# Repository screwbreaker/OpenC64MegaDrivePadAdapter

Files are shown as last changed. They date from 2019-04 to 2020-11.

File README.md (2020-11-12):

# OpenC64MegaDrivePadAdapter
OpenC64MegaDrivePadAdapter is an Open Hardware adapter that allows the safe connection of a Sega Mega Drive (known as *Genesis* in the US) controller to a Commodore 64 or Amiga computer.

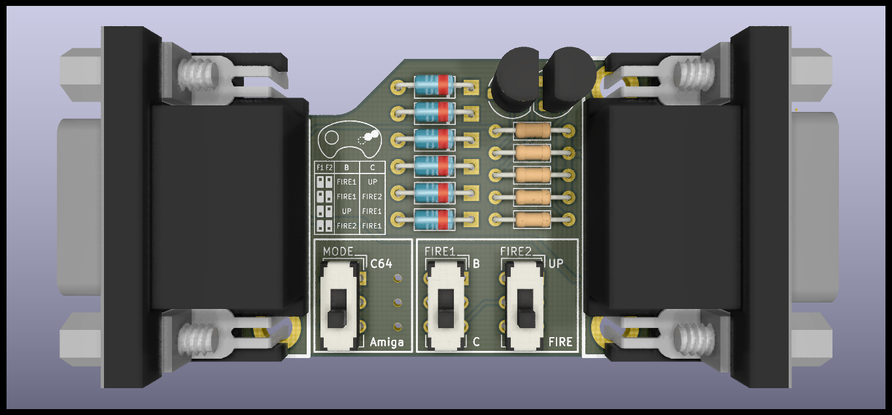
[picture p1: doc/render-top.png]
Board


### Synopsis
This board is a fork of a project of SukkoPera: [github.com/SukkoPera](https://github.com/SukkoPera/), also this document is based on the original version.

The original version of this board can be found here: [github.com/SukkoPera/OpenC64MegaDrivePadAdapter](https://github.com/SukkoPera/OpenC64MegaDrivePadAdapter)

In this version the PCB has a particular shape in order to manage with the Amiga 600 case.
A manual cut of the DB9 connector still required in order to allow this adapter to fit into the A600 port 2. If you are not confident with cut tools, don't do it! A simple extension cable is a perfect and easy solution for this problem. 

This version use switches instead jumpers, this make the configuration much easier, plus now is impossible to set an improper configuration.
Is still recommended to turn off the computer before change the configuration.
The UP direction on the D-PAD is always active, it cannot be disabled. It can be used together with another button configured as UP. An extra diode (D6) is used to separate the two UP lines.

In the older versions of the adapter, sometimes the second button was not recognized by some games, now a transistor is used to fix this issue.
This version is also compatible with the [OpenAmigaJoyMouseSwitcher](https://github.com/SukkoPera/OpenAmigaJoyMouseSwitcher).

Rev 6 also include the mod to allow the amiga to use all the MD pad buttons. Unfortunately at the moment there are no known games or program that can do this. Thanks to SukkoPera for this improvement.

### Summary
Despite being compatible at the physical level (i.e.: they use the same DB-9 connectors), Sega Mega Drive controllers are slightly different from the *Atari-style joysticks* (which the C64 uses) at the electrical level. These differences usually manifest themselves in the fact that certain keyboard keys are not responsive when a Sega Mega Drive pad is connected to a C64 computer, but the CIA chip may also get harmed as a result.

Since I think that the Sega Mega Drive controller is one of the best joypads which ever saw the light, I developed this simple adapter board, which is supposed to sit inbetween the computer and the controller. You should be able to keep it plugged into the computer and then connect the controller to it, but you can also use a joystick extension cord (widely available), if that makes it easier.

Button B will work as the normal fire button, but this adapter also allows using Button C as the second fire button, for those games that support two buttons.

While this all works out of the box on Amiga computers, this adapter also allows to customize the button mapping to a certain degree: for instance, replacing UP with C might make some games more comfortable to play. This might be useful on the Amiga as well, so the adapter also supports an Amiga mode.

In this version the D-PAD UP is always active, it ca be used in games as usual, this is andy for games witch use UP for multiple things: menu, jump, go upstairs, etc.

### Configuration
The board is based on the circuit that was originally published in [issue #5 of Commodore world](https://www.scribd.com/document/8945979/Commodore-World-Issue-05) back in 1994, with a few improvements that will allow an easier gameplay with certain titles.

First of all, be sure to move the C64/Amiga switch to the proper position, before connecting the adapter.

Since most joysticks back in the day only had a single fire button, it was usually used for *firing*, whatever that meant. *Jumping* was usually done with the UP direction of the joystick, which is quite annoying on a joypad.
This is why OpenC64MegaDrivePadAdapter allows you to repurpose the B or C key to jumping, leaving the other button for firing, all at your choice.
It also allows to use C as the second fire button, which is only supported by a few titles. You can even swap B and C, if you prefer.

The switches configurations are showed on a little table printed on the board. F1 and F2 on the table refers to FIRE1 and FIRE2 switches.

The FIRE1 switch select which button to use as FIRE 1, B or C.

The FIRE2 switch select which action the FIRE 2 button must perform, UP (the same of the D-PAD UP) or FIRE.

**ALWAYS TURN YOUR COMPUTER OFF BEFORE MOVING THE CONFIGURATION SWITCHES.**
If you don't follow this rule, **you will probably cause permanent damage to your computer and/or controller**, so **please be careful**, you have been warned.

### Compatibility
This adapter is compatible with every MD gamepad, even the 6 buttons one. And also with the Master System gamepad.

The Mega Drive gamepad is designed to be back compatible with the Master System. B and C on the Mega Drive are BUTTON 1 and BUTTON 2 on the Master System.

To add more buttons on the Mega Drive, SEGA added an extra line (SELECT) wich is toggled HIGH or LOW. The state of this line determinate wich set of buttons the pad must return (B and C or A and START).
Since in this adapter the SELECT line is always HIGH, only the B and C buttons are used.

### License
OpenC64MegaDrivePadAdapter is Open Hardware. If you make any modifications to the board, please contribute them back.

### Support the Project
Since the project is open you are free to get the PCBs made by your preferred manufacturer, however in case you want to support the development, you can order them from PCBWay:

PCB from PCBWay (https://www.pcbway.com/project/shareproject/OpenC64MegaDrivePadAdapter.html)

You get cheap, professionally-made and good quality PCBs, the autor of the board get some credit that will help with this and [other projects](https://www.pcbway.com/project/member/?bmbno=W123483A). You won't even have to worry about the various PCB options, it's all pre-configured for you!

Also, if you still have to register to that site, [you can use this link](https://www.pcbway.com/setinvite.aspx?inviteid=41100) to get some bonus initial credit (and some more to the author).

Again, if you want to use another manufacturer, feel free to, don't feel obligated :).

### Get Support
If you need help or have questions, you can join [the official Telegram group](https://t.me/joinchat/HUHdWBC9J9JnYIrvTYfZmg).

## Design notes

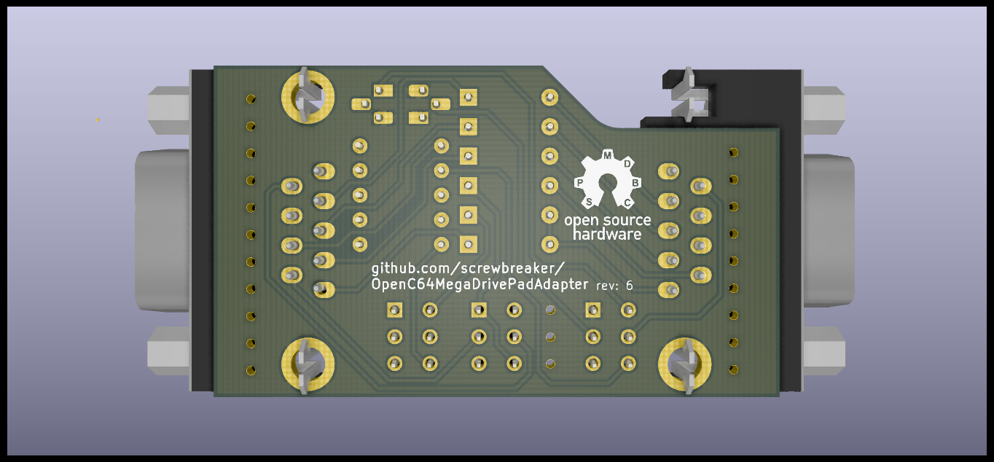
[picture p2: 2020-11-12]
doc/render-bottom.png

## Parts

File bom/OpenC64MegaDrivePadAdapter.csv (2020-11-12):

Id | Designator | Package | Quantity | Designation | Supplier and ref
1 | Q2,Q1 | TO-92_Molded_Narrow | 2 | BC547
2 | D4,D6,D1,D2,D3,D5 | D_DO-35_SOD27_P7.62mm_Horizontal | 6 | 1N4148
3 | R1,R2,R3,R4,R5 | R_Axial_DIN0204_L3.6mm_D1.6mm_P7.62mm_Horizontal | 4 | 10k
4 | S1,S2,S3 | SW_CuK_JS202011CQN_DPDT_Straight | 3 | JS202011CQN
5 | J20 | DB_9M | 1 | DB9_M_TO_PAD
6 | J10 | DB_9F | 1 | DB9_F_TO_C64

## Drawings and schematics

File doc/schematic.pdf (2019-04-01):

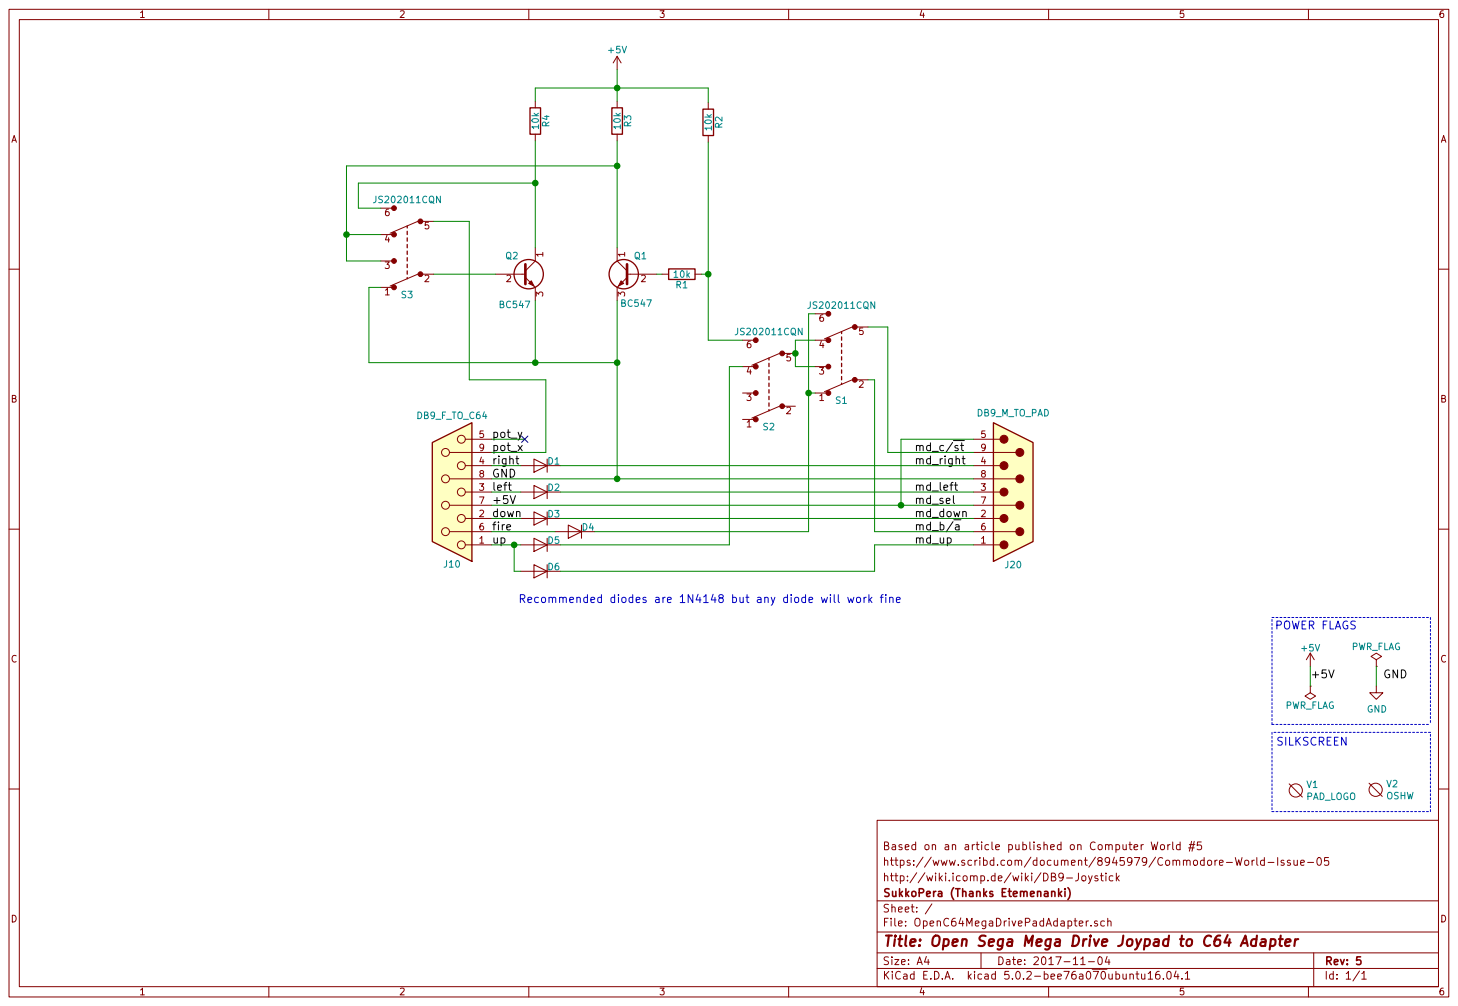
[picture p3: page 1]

J20 DB9_M_TO_PAD Recommended diodes are 1N4148 but any diode will work fine

https://www.scribd.com/document/8945979/Commodore-World-Issue-05
http://wiki.icomp.de/wiki/DB9-Joystick
File: OpenC64MegaDrivePadAdapter.sch Sheet: / SukkoPera (Thanks Etemenanki)

Id: 1/1 Title: Open Sega Mega Drive Joypad to C64 Adapter

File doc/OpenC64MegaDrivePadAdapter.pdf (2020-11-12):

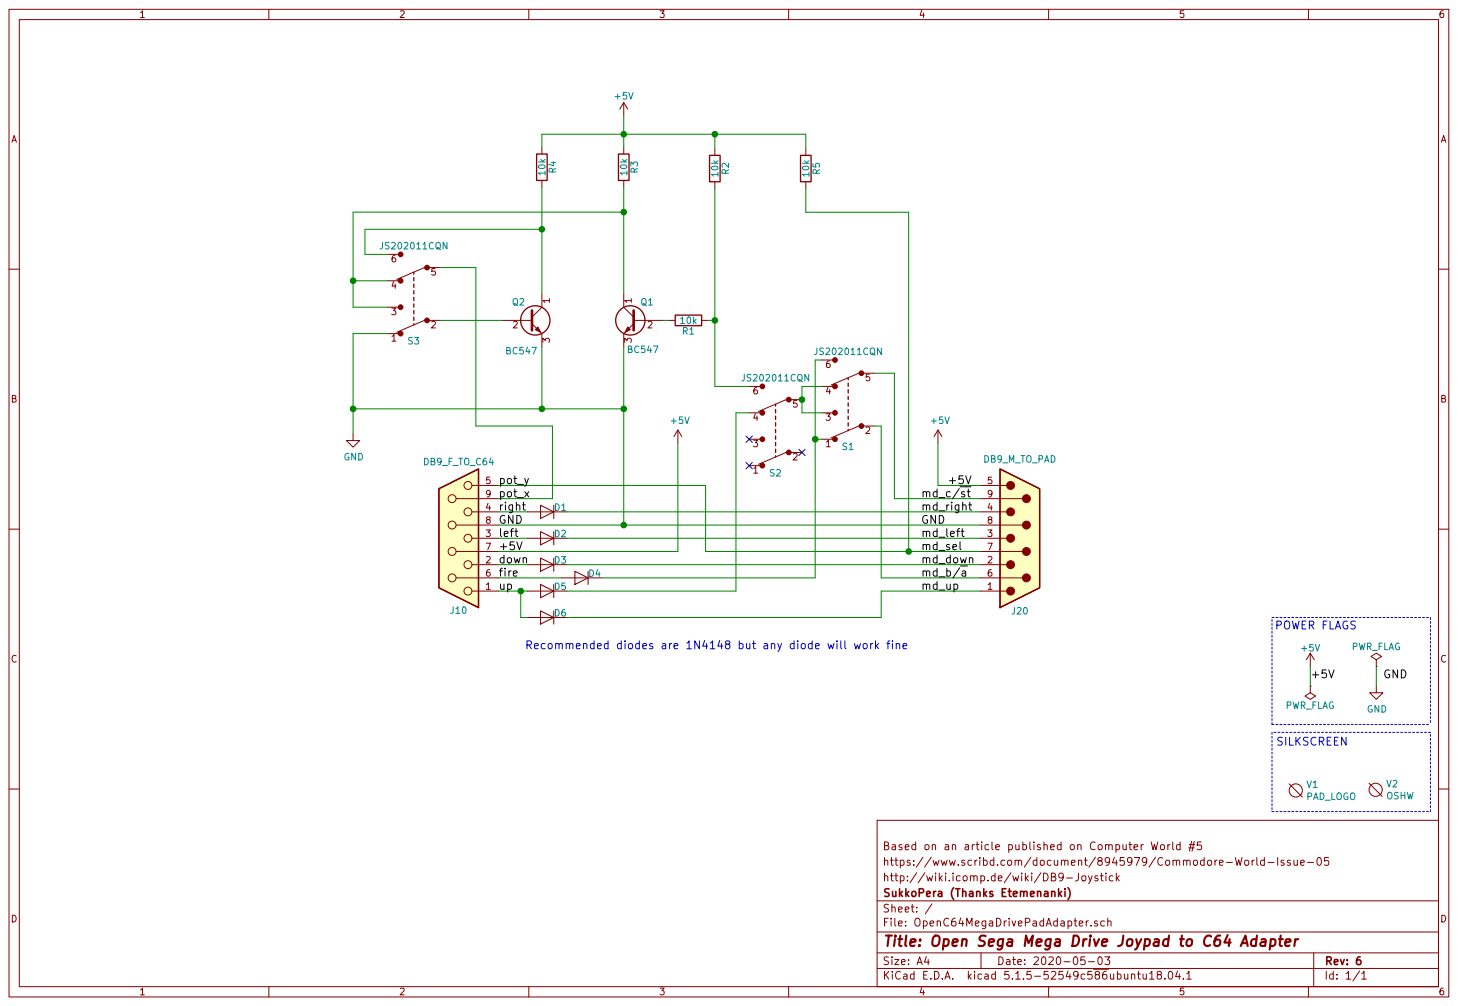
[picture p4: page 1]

Recommended diodes are 1N4148 but any diode will work fine

Based on an article published on Computer World #5
https://www.scribd.com/document/8945979/Commodore-World-Issue-05
http://wiki.icomp.de/wiki/DB9-Joystick
File: OpenC64MegaDrivePadAdapter.sch Sheet: / SukkoPera (Thanks Etemenanki)

Id: 1/1 Title: Open Sega Mega Drive Joypad to C64 Adapter

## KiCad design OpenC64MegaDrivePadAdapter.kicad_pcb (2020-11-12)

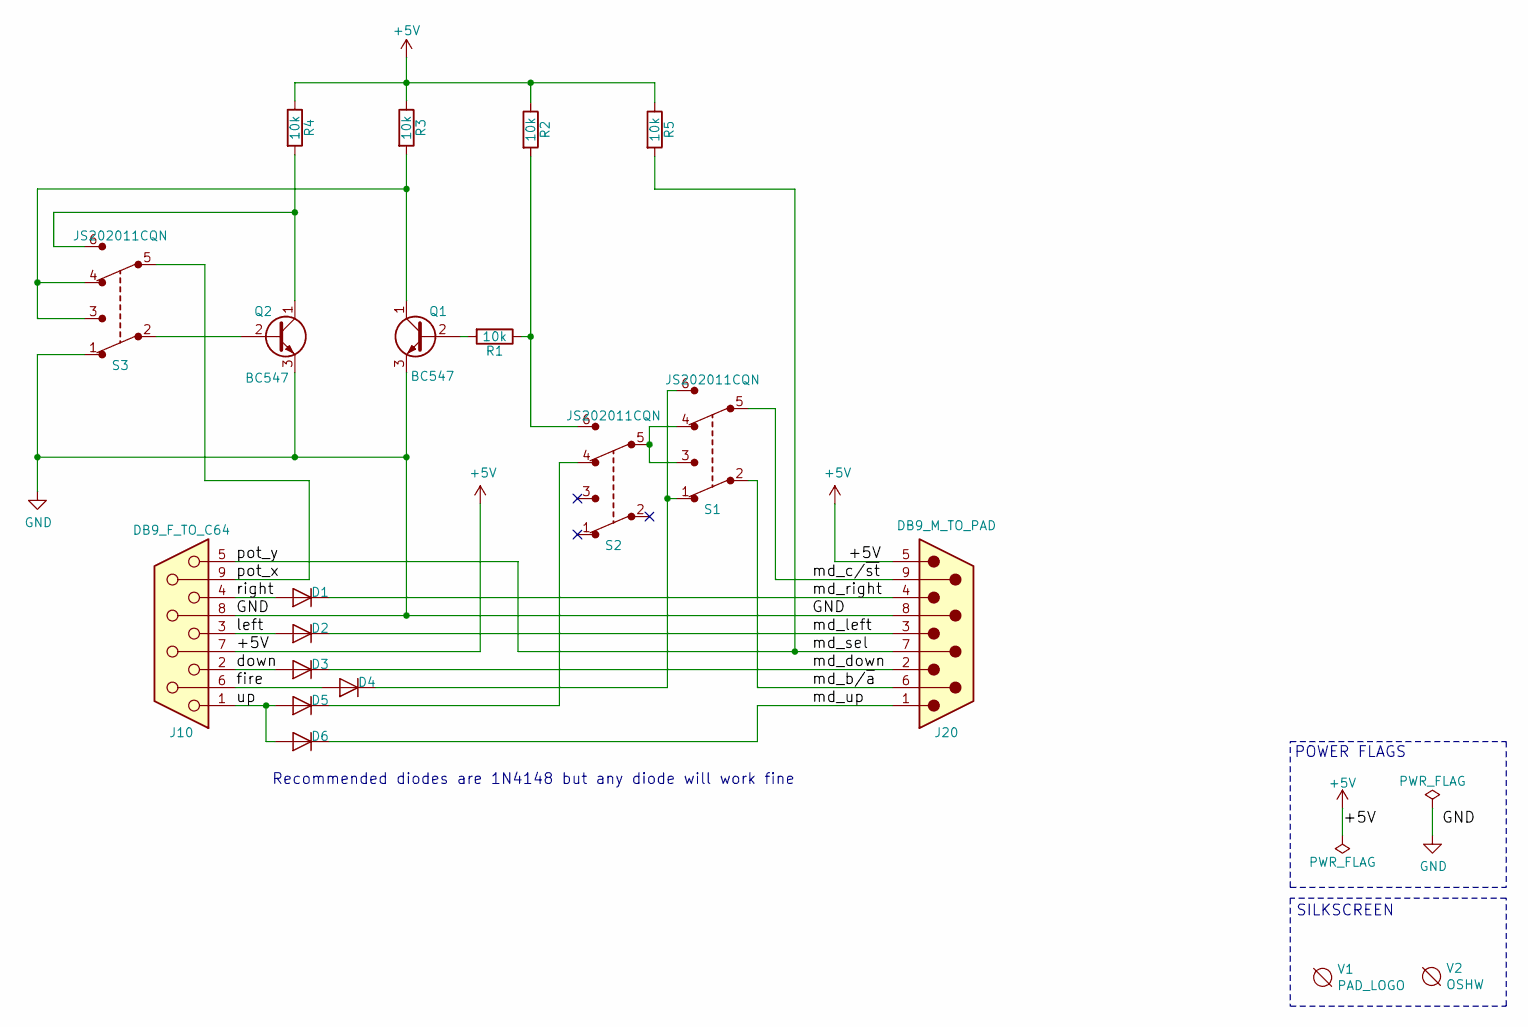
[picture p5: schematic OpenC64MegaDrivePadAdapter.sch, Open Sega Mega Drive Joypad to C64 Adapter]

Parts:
D1, D2, D3, D4, D5, D6: 1N4148; D_DO-35_SOD27_P7.62mm_Horizontal
J10: DB9_F_TO_C64; DB_9F
J20: DB9_M_TO_PAD; DB_9M
Q1, Q2: BC547; TO-92L_HandSolder
R1, R2, R3, R4, R5: 10k; R_Axial_DIN0204_L3.6mm_D1.6mm_P7.62mm_Horizontal
S1, S2, S3: JS202011CQN; SW_CuK_JS202011CQN_DPDT_Straight; MPN JS202011CQN; Digi-Key_PN 401-2001-ND
V1: PAD_LOGO; LOGO
V2: OSHW; oshw

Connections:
+5V: J10.7, J20.5, R2.1, R3.1, R4.1, R5.1
/down: D3.2 (A), J10.2
/fire: D4.2 (A), J10.6
/left: D2.2 (A), J10.3
/md_b/~a: J20.6, S1.2
/md_c/~st: J20.9, S1.5
/md_down: D3.1 (K), J20.2
/md_left: D2.1 (K), J20.3
/md_right: D1.1 (K), J20.4
/md_sel: J10.5, J20.7, R5.2
/md_up: D6.1 (K), J20.1
/pot_x: J10.9, S3.5
/right: D1.2 (A), J10.4
/up: D5.2 (A), D6.2 (A), J10.1
GND: J10.8, J20.8, Q1.3 (E), Q2.3 (E), S3.1
unnamed: D4.1 (K), S1.1, S1.6
unnamed: D5.1 (K), S2.4
unnamed: Q1.1 (C), R3.2, S3.3, S3.4
unnamed: Q1.2 (B), R1.2
unnamed: Q2.1 (C), R4.2, S3.6
unnamed: Q2.2 (B), S3.2
unnamed: R1.1, R2.2, S2.6
unnamed: S1.3, S1.4, S2.5

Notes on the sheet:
Recommended diodes are 1N4148 but any diode will work fine
SILKSCREEN
POWER FLAGS

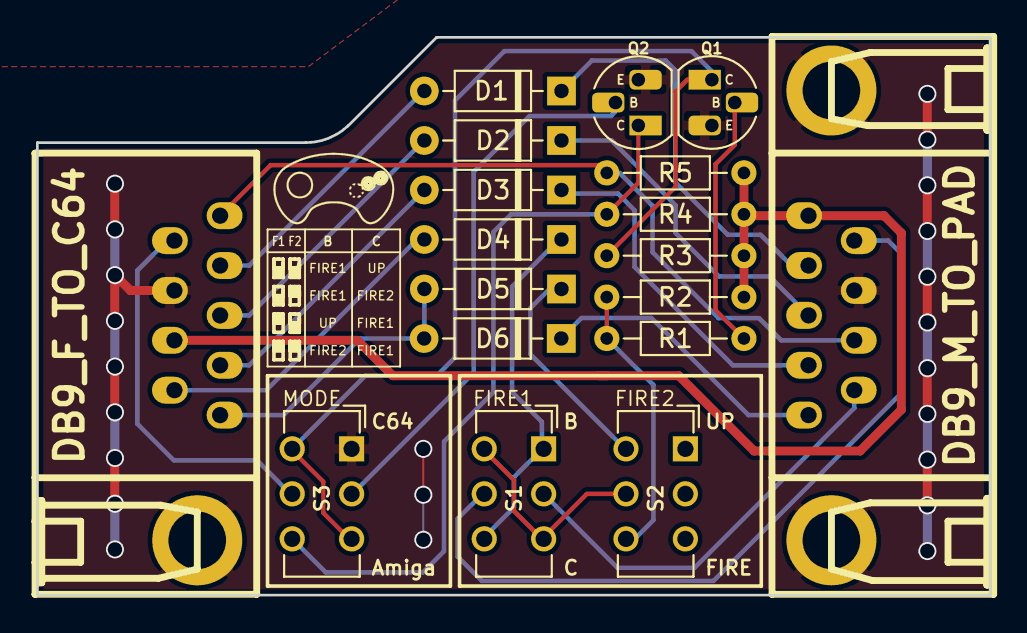
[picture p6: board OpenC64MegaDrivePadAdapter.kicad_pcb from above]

Board: 2 copper layers, 52.9 x 31.0 mm, 20 parts (1 on the bottom side), 23 nets.

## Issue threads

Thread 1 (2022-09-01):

V6 schematics causes rapid ghost left/right events on C64 joystickport1

rainisto, 2022-09-01:
If I revert back to V5 by putting jumper wire on R5 ghost events disappear on C64 joystickport1. Port2 works normally,

screwbreaker, 2022-09-02:
I'm working on a new revision.
To fix the issue I'm working on a version where R5 still in place. But pot_y is disconnected in the C64 mode.

screwbreaker, 2022-12-03:
I released the v7
The issue should be fixed.
I tested it on both Amiga and C64, and I have no issue.

Closed 2023-08-29.

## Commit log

2018-12-31 Align connectors to board edge, move button 2 to pin 9
2018-12-31 V4 renders and schematics
2018-12-31 DB9 connector
2018-12-31 Align connectors to board edge
    Align connectors to board edge, move button 2 to pin 9
2018-12-31 V4 schematics
    [OpenC64MegaDrivePadAdapter.sch]
2018-12-31 V4 PCB
    [OpenC64MegaDrivePadAdapter.kicad_pcb]
2019-01-01 Interactive BOM
2019-01-09 Bill of Materials
    [OpenC64MegaDrivePadAdapter.csv]
2019-01-09 Void element for silk screen
    This is a void element to keep on the footprints with only the silk screen on the PCB
2019-01-09 Minor changes
    [OpenC64MegaDrivePadAdapter.kicad_pcb]
2019-01-09 Added voids elements for the silk screen
    [OpenC64MegaDrivePadAdapter.sch]
2019-04-01 Delete OpenA1200RTC.csv
    wrong project
    [OpenA1200RTC.csv]
2019-04-01 rev. 5 renders and schematics
2019-04-01 rev. 5 PCB
    [OpenC64MegaDrivePadAdapter.kicad_pcb]
2019-04-01 rev. 5 schematics
    [OpenC64MegaDrivePadAdapter.sch]
2020-11-12 rev. 6 renders and schematics
2020-11-12 rev 6
    [OpenC64MegaDrivePadAdapter.kicad_pcb, OpenC64MegaDrivePadAdapter.sch]
